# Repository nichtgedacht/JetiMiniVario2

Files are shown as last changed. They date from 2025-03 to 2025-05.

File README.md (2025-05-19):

# JetiMiniVario2

## What it is
JetiMiniVario2 is a variometer and altimeter.
Optionally, a Ublox GNSS module (M8 or M10) can be connected.

JetiMiniVario was developed to detect smallest air movements with a DLG.

Communication with the GNSS (GPS) device is done using the UBX protocol over UART.
If the device is set to 9600 baud before (factory setting) the necessary
configuration is done automatically. The NavPvt data set with 10Hz refresh rate
is used. The serial interface works with 19200 baud.

Communication with the RC-receiver (Jeti EX Bus) is done with a low level 
configured UART Peripheral at 125000 Baud. It works half duplex on a single pin.
The DMA is used in order to achieve a proper timing without collisions.

Communication with the sensor boards is done over I2C at 500kHz. 

JetiMiniVario2 is built from the following components:

 * A MCU board Seeed Studio XIAO (SAMD21G18)

 * One or two shield boards with the SPL06-001 Barometric Pressure Sensor

 * A GNSS device with a M8 or M10 module from Ublox. (i.e. Beitian BN-XXX BE-XXX, FlyfishRC M10 mini, ...) 

JetiMiniVario is optimized for very short response times
with low noise. Due to a free RC channel the filtering can be
adjusted continuously and thus the variometer can be be calmed down.
A gas-tight volume is provided between the sensor boards.
By encapsulating the sensor PCBs with thin epoxy plates and attaching
a tube connection one sensor can be connected to a TEK probe. 

A voltage divider 1:10 (recommended 2k and 18k each 0.1%) can be connected
to PIN_A8. The 3.3V are used as reference so a voltage up to 33V can be
applied. Accuracy is 1/100 V if calibrated, see below.

Up to 4 Servos can be connected. The timing of the pulses (period) can
be adjusted from 10 to 40 ms. The mapping to the RC-channels of the the
EX-Bus is arbitary. Failsave positions can be adjusted for each servo.
The time from a fail to failsave is adjustable also.

There is a watchdog which monitors the main loop. If the loop time
exceeds 7.8 ms all sensors are bypassed and a fuse becomes triggered
within the configuration. If the loop time exceeds even 31 ms a system
reset becomes triggered also. This way the servo control is save in
case of a sensor hardware is blocking or delaying the loop.

The fuse can be set again by the terminal, see below.

Please use the bootloader from here:
https://github.com/adafruit/uf2-samdx1/releases
This bootloader has the brown-out detector implemented.
It prevents bootloader corruption due to unclean power cycles.
Please find it also within the UF2 folder.

## Mechanical design

The device can be assembled from several hardware parts according
to your individual needs. It could be a very small thing with the MCU-board only
or the full featured device with a baseboard.

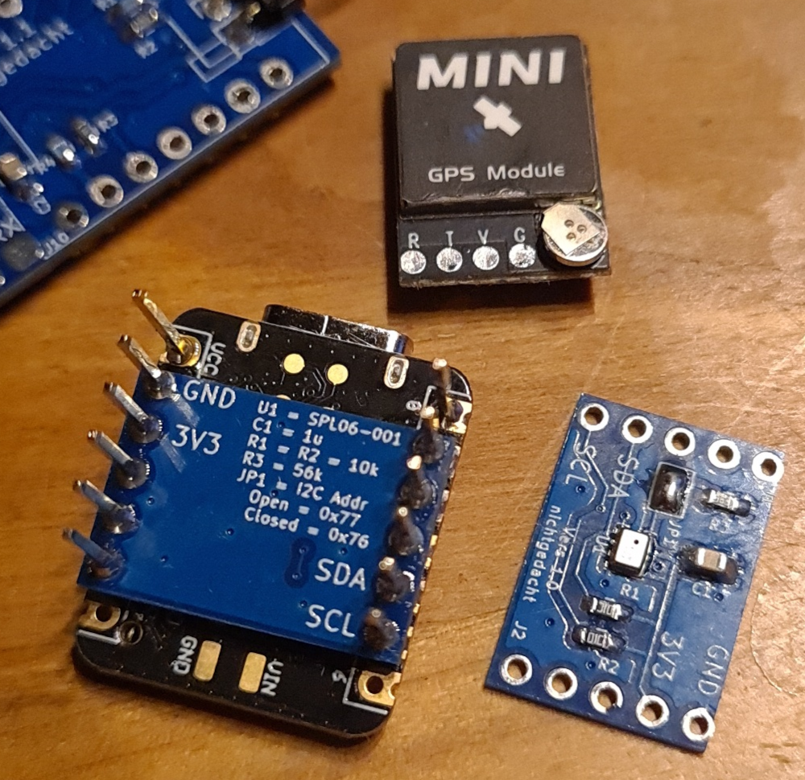
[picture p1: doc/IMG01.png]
  
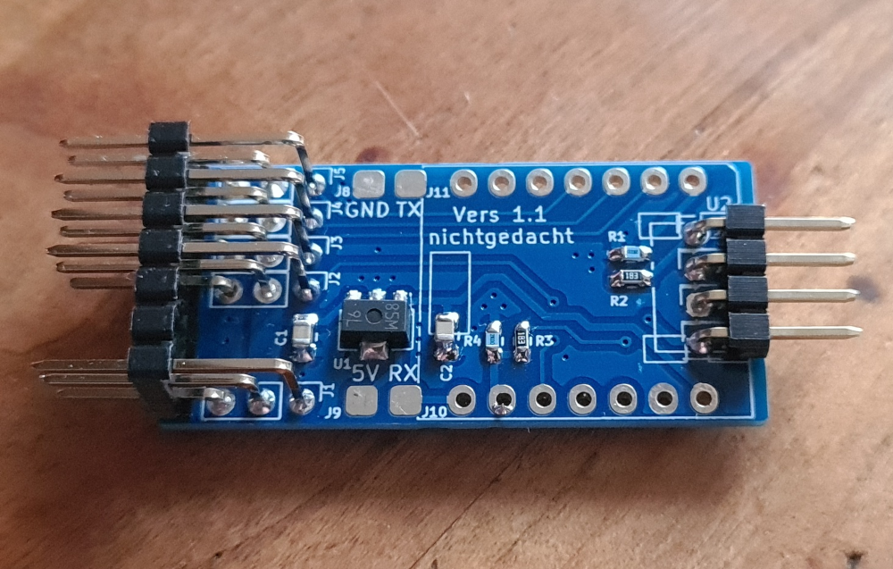
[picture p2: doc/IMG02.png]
  

The Sensor PCB has a Solder Jumper for changing the I2C address.
If 2 PCB's are in use, the sensor vwith the changed address becomes the
encapsulated one for TEK connection.  

First set the alternative address on one of the Sensors:  
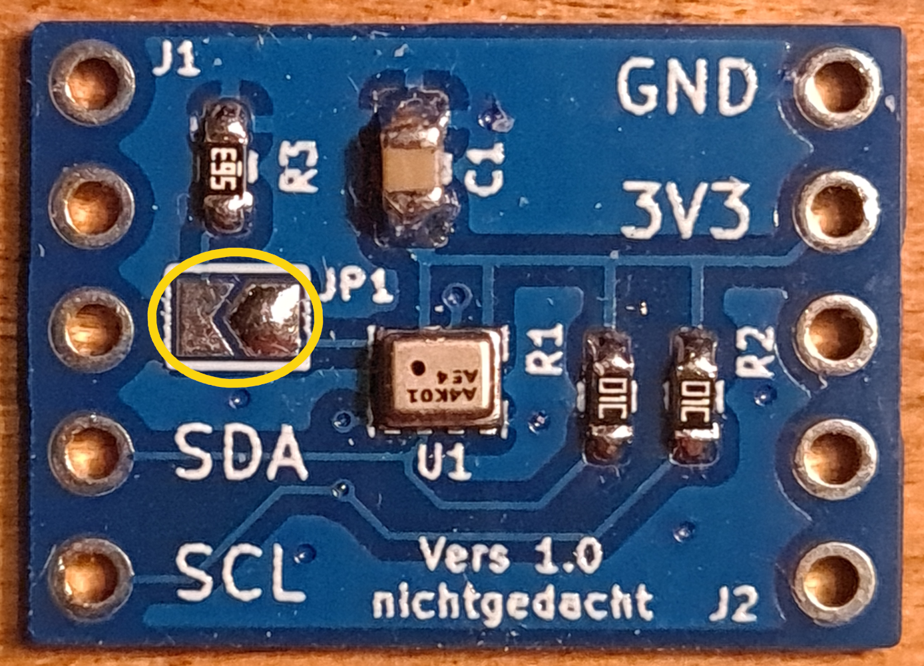
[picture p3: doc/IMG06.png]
  

In order to encapsulate a volume by the 2 sensor PCB's 
make both PCBs gasproof by using some epoxy on this sides:  
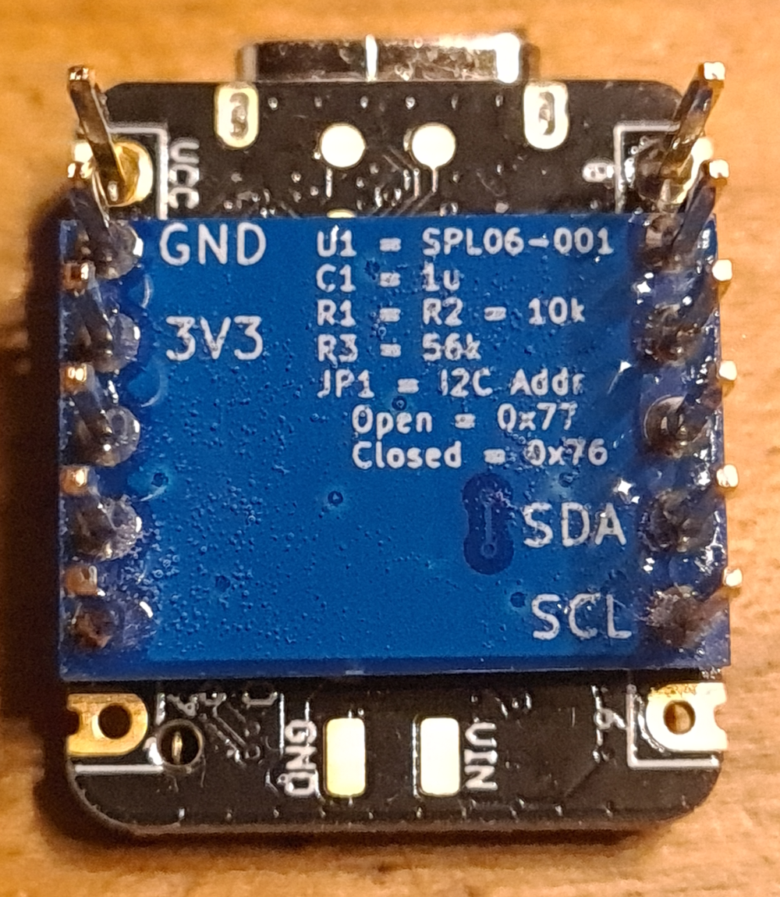
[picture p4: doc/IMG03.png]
  

The sensor PCB's then can be stacked and encapsulate an air volume together with small epoxy stripes
Please refer to first version of JetiMiniVario:  
  

Top view
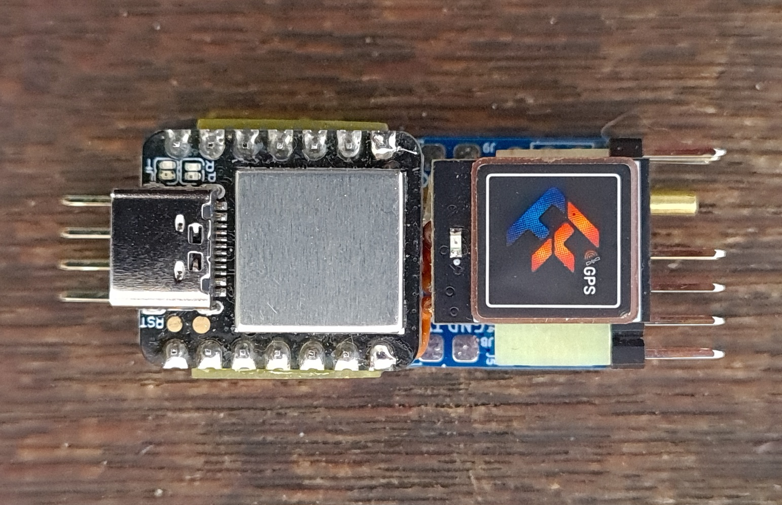
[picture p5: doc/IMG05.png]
  

Sensor PCB:  
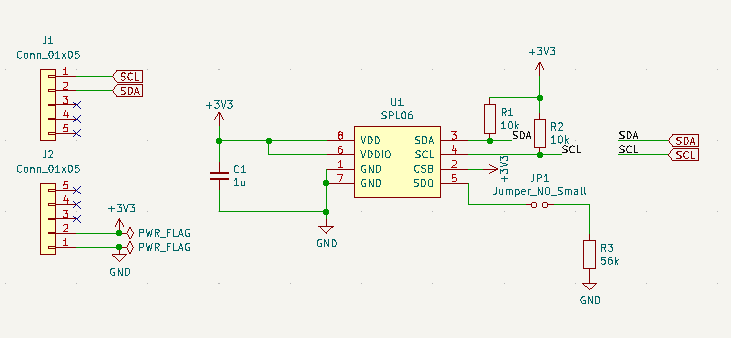
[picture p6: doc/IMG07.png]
  

Base PCB:  
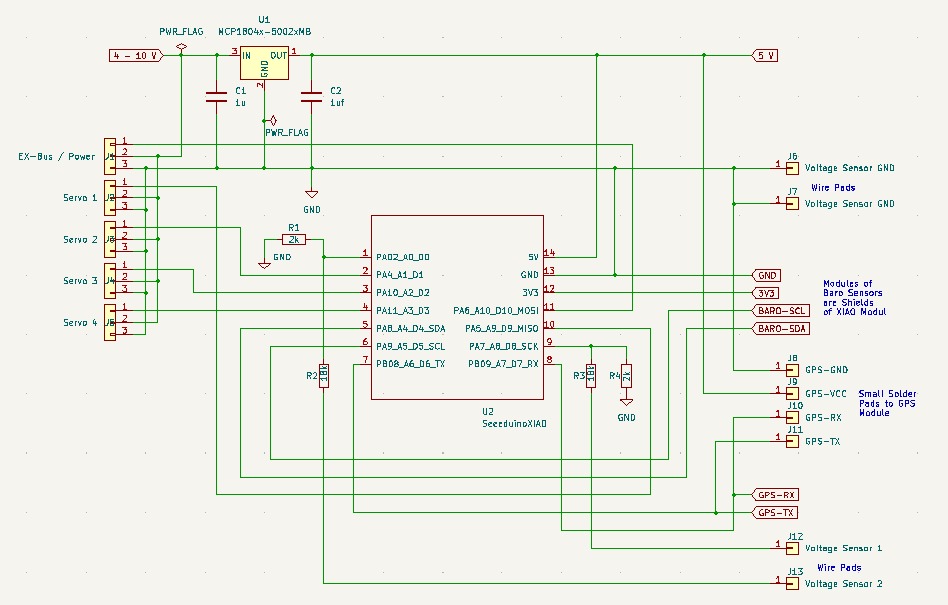
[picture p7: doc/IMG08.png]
  

## Electrical limits

JetiMiniVario can be powered by the RC receiver.
The voltage should not not exceed 6V. The voltage regulator
on the XIAO has 7V as absolut maximum rating. 4 cells of NiMh
are probably ok. But most GNSS-modules are specified for max 5.5V
So it's better using a 5.5V BEC or an onboard LDO regulator like the
AMS1117 5.0V type, if the input voltage exceeds 5.5V. The current baseboard
uses an MCP1804 5V type. Power from 1 cell LiPo is perfectly ok for the
device itself and the GNSS-modul. The 3.3V regulator of the XIAO can power
the baro-sensor-pcbs VCC-pins in any setup.

## Software

### Libraries

The software uses two libraries:
* DPS
* JetiExBus

To load the two libs at the same time you can use this command line:

git clone --recursive https://github.com/nichtgedacht/JetiMiniVario2.git 
 
### IDE 
 
The repository here is to be used directly as a PlatformIO project.
It is as simple as:

* Install VSCode

* In VSCode install the PlatformIO extension. (Search by typing Plat...)

* Within PlatformIO open the directory of the repository as a project.
 
Because the Arduino Framework is used, the code can also be compiled in the Arduino IDE. 
For this, the extension for the SeedStudio XIAO must be installed first.
Then main.cpp must be renamed to JetiMiniVario.ino.
The correct board can then be selected in the board selection.

### Upload

Until the GNSS module was connected, the software was developed with a BlackMagicProbe
which also used the serial interface at A6 A7. 
The upload was done via the debug interface. In the current configuration
the upload is done via the USB-C connector.
It is of course still possible to work with the BlackMagicProbe if the
debug Serial.print goes through the USB-C connector. See "platformio.ini".
<BR>
<BR>
You can upload also one of the UF2 files:
* Short the reset contacts 2 times within 1/2 second.
* The yellow LED will slowly dim blink.
* The device will then register as mass storage
* Copy the UF2 file there

### LED Signals of application

* Yellow LED blinks 1Hz

For configurations without SERVO and with BARO (DUAL).<br>
Baro Hardware is missing or broken.<br>
Terminalserver can not be reached in this state.

* RX- and TX-LED (blue) solid on

For configurations with SERVO.<br>
Watchdog has triggered the fuse. Reset fuse with a terminal <br>
after checking the hardware.

* Yellow LED blinks 10Hz.

Normal operation with GPS (GNSS-modul).

* RX- and TX-LED (blue) and yellow LED solid on

Hard fault

### Configuration

There are only these defines at the beginning of config.h:
* //#define DEBUG // debug prints or not

* #define BARO // using a barometric pressure sensor<br>

* #define DUAL // using an additional barometric pressure sensor<br>

    If dual pressure sensors are used one is for the variometer and the other becomes<br>
    altitude.

* #define GPS  // using the GNSS Modul<br>

* #define VOLT // using the ADC<br>

* #define SERVO // enable servo output<br>
 
These defines depends on the assembled hardware. Please comment out what is not used<br>
or use the appropriate UF2 file
<br>
<br>

All other configuration can be done with a Command-Line-Interface:  

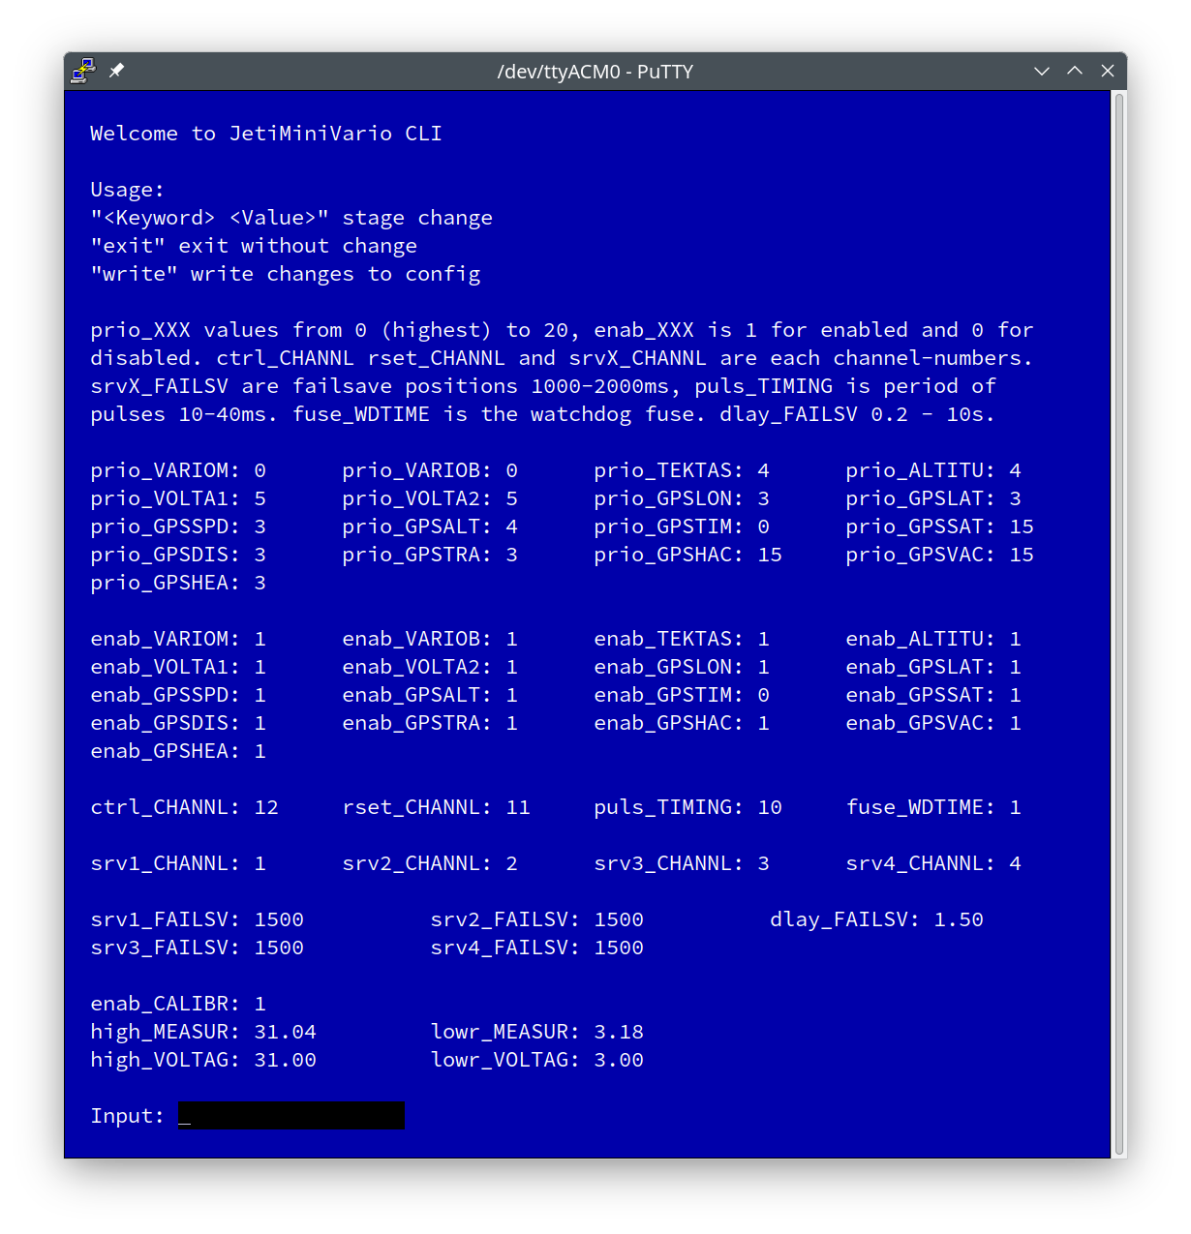
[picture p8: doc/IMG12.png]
  

The following items can be configured with the CLI

* The RC-channel used for live adjusting the filters.<br>

  This RC-channel-value is assumed to go from 1000us to 2000us.<br>
  Time constants (Taus) of the main filter are then adjustable from about 0.4s (at 1000us)<br>
  to about 0.8s (at 2000us)<br>

* The RC-channel used to reset altitude and GNSS home position<br>

  The transition of channel value for reset must go from higher to lower<br>
  and difference must be greater than 300 (e.g. from 2000 to 1000 ).<br>
  Hint: Use the Servo Monitor. The transition must be instantanuosly.<br>
  If this switch is used for changing a flight mode also and there is a delay<br>
  i.e. a soft transition the reset will not work

* Priority of a sensor<br>

* Enable/disable a sensor<br>  

* The RC-channel-mapping to the servo outputs<br>  

* Period of servo pulses timing in ms<br>  

* Failsave positions in micro s<br>  

* Delay to failsave in s<br>  

* Fuse of watchdog timer reset/set<br>  
 
* Calibrate the voltage sensor (ADC)<br>  

For calibrating the voltage sensor:
* Disable calibration
* Apply a voltage arround 3V
* Read the measured voltage
* Change the values for applied and measured voltages
* Do the same for a voltage arround 30V
* Enable calibration
* Write changes

Note that this calibration works precisely only for
the selected pin (VOLTA1 or VOLTA2). The deviation
of the other voltage then depends on the accuracy of
the choosen resistors.    

Legend:
* VARIOM Variometer
* VARIOB in DUAL-setup Variometer from static port no TEK
* TEKTAS True Airspeed calculated from Pressure Diff of TEK-Probe
* ALTITU Barometric Altitude
* VOLTA1 Voltage1
* VOLTA2 Voltage2
* GPSLON GPS Longtitude
* GPSLAT GPS Latitude
* GPSSPD GPS Speed
* GPSALT GPS Altitude
* GPSTIM GPS Time
* GPSSAT Number GPS Vehicles in use
* GPSDIS Calculated Value of GPS Distance to Home Position
* GPSTRA Calculated Value of GPS Travel Distance
* GPSHAC GPS Horizontal Accuracy
* GPSVAC GPS Vertical Accuracy
* GPSHEA GPS Bearing

As terminal emulation Putty can be used. The default settings<br>
of Putty are ok.<br>
* Just select the serial interface connected to the device<br>
* At least 83x38 (rows x colums) are needed for a complete window.<br>
* For proper viewing an 11 point Monospace Font is recommended.<br> 
* Putty is available for Linux, and Windows.

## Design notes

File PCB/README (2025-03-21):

View a Set of Gerbers by uploading to https://tracespace.io/view/

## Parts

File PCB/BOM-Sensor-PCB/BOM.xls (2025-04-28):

Comment | Designator | Footprint | JLCPCB Part#(optional)
1uF | C1 | 0805 | C28323
10k | R1, R2, R3 | 0603 | C25804
SPA06-003 | U1 | LGA8 | C30589048

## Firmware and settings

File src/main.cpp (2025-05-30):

#include "JetiExBusProtocol.h"  //	https://github.com/nichtgedacht/JetiExBus
#include <Wire.h>
#include "DPS.h"                //	https://github.com/nichtgedacht/DPS2
#include "config.h"

config_t cfg;

JetiExBusProtocol exBus;

// Connect to DPS
DPS dpsA;  // gets DPS_ADDR_DEF 0x77
DPS dpsB;  // gets DPS_ADDR_ALT 0x76

#define T1 150000.0 // base time constant
#define T2 200000.0 // base time constant
double t1 = T1;
double t2 = T2;

#define deltaTA 31250  // measured value differs a bit from
                       // device to device nominal value could
#define deltaTB 31250  // be 5% off or so.

// set neutral
uint16_t channelValue = 1500;
uint16_t prevChannelValue = 1500;

bool servoRun = false;
bool wdRun = false;
ulong rcWatch;

bool resetHome = true;
double latHome;
double lonHome;
double latLast;
double lonLast;
uint32_t travel = 0;

ulong blink;

volatile bool wdTimeout = false;

long mue = 0;
long mueDiff = 0;
long prevMue = 0;
long worstMueDiff = 0;
unsigned long loopCount = 0;


//uint32_t mic, prevmic, micDiff;
//double micDiffAvr;
//char micDiffAvr_string[20];

long realPressureA, realPressureB;
int32_t pressureA[1], pressureB[1];
int32_t temperatureA[1], temperatureB[1];

#ifdef GPS
// sets refresh rate
char refresh_10hz[] = { 0xb5, 0x62, 0x06, 0x08, 0x06, 0x00, 0x64, 0x00,
                        0x01, 0x00, 0x01, 0x00, 0x7a, 0x12 };

// sets messages 
char ubx_nav_pvt[] = { 0xb5, 0x62, 0x06, 0x01, 0x08, 0x00, 0x01, 0x07,
                       0x00, 0x01, 0x00, 0x00, 0x00, 0x00, 0x18, 0xe1 };

// sets port
char prt_ubx_only_19200[] = { 0xb5, 0x62, 0x06, 0x00, 0x14, 0x00, 0x01, 0x00,
                              0x00, 0x00, 0xd0, 0x08, 0x00, 0x00, 0x00, 0x4b,
                              0x00, 0x00, 0x07, 0x00, 0x01, 0x00, 0x00, 0x00,
                              0x00, 0x00, 0x46, 0x4b };


char enable_galileo[] = { 0xb5, 0x62, 0x06, 0x3e, 0x0c, 0x00, 0x00, 0x00,
                          0x20, 0x01, 0x02, 0x04, 0x08, 0x00, 0x01, 0x00,
                          0x01, 0x01, 0x82, 0x56 };
#endif

enum {
    ID_DUMMY = 0,
#ifdef BARO
    ID_VARIOM,
#ifdef DUAL
    ID_VARIOB,
    ID_TEKTAS,
#endif
    ID_ALTITU,
#endif
#ifdef GPS
    ID_GPSLON,
    ID_GPSLAT,
    ID_GPSSPD,
    ID_GPSALT,
    ID_GPSTIM,
    ID_GPSVEH,
    ID_GPSDIS,
    ID_GPSTRA,
    ID_GPSHAC,
    ID_GPSVAC,
    ID_GPSHEA,
#endif
#ifdef VOLT
    ID_VOLTA1,
    ID_VOLTA2,
#endif
};

#ifdef BARO
double referencePressureA = 0, referencePressureB = 0, offsetPressureB = 0;
double r_altitudeA = 0, r_altitude0A = 0, r_altitudeB = 0, r_altitude0B = 0; 
double climbA = 0, climb0A = 0, climbB = 0, climb0B = 0; 
double dyn_alfaA, dyn_alfaB, alfa_1A, alfa_2A, alfa_1B, alfa_2B, factor;

uint32_t diff_t_A, max_diff_t_A, diff_t_B, max_diff_t_B;
double relativeAltitudeA = 0, relativeAltitudeB = 0;
#endif

#ifdef VOLT
double avar1 = 0;
double avar2 = 0;
uint16_t GAIN_CORR;
uint16_t OFFSET_CORR;
bool adcStart = true;
#endif
int j=0;

#ifdef GPS
//-------------------- UBX ----------------------------

typedef union {

    struct {
                                /* Comments stohlen from PX4 */
	    uint32_t iTOW;          /**< GPS Time of Week [ms] */
	    uint16_t year;          /**< Year (UTC)*/
	    uint8_t  month;         /**< Month, range 1..12 (UTC) */
	    uint8_t  day;           /**< Day of month, range 1..31 (UTC) */
	    uint8_t  hour;          /**< Hour of day, range 0..23 (UTC) */
	    uint8_t  min;           /**< Minute of hour, range 0..59 (UTC) */
	    uint8_t  sec;           /**< Seconds of minute, range 0..60 (UTC) */
	    uint8_t  valid;         /**< Validity flags (see UBX_RX_NAV_PVT_VALID_...) */
	    uint32_t tAcc;          /**< Time accuracy estimate (UTC) [ns] */
	    int32_t  nano;          /**< Fraction of second (UTC) [-1e9...1e9 ns] */
	    uint8_t  fixType;       /**< GNSSfix type: 0 = No fix, 1 = Dead Reckoning only, 2 = 2D fix, 3 = 3d-fix, 4 = GNSS + dead reckoning, 5 = time only fix */
	    uint8_t  flags;         /**< Fix Status Flags (see UBX_RX_NAV_PVT_FLAGS_...) */
	    uint8_t  flags2;        /**< Additional flags */
	    uint8_t  numSV;         /**< Number of SVs used in Nav Solution */
	    int32_t  lon;           /**< Longitude [1e-7 deg] */
	    int32_t  lat;           /**< Latitude [1e-7 deg] */
	    int32_t  height;        /**< Height above ellipsoid [mm] */
	    int32_t  hMSL;          /**< Height above mean sea level [mm] */
	    uint32_t hAcc;          /**< Horizontal accuracy estimate [mm] */
	    uint32_t vAcc;          /**< Vertical accuracy estimate [mm] */
	    int32_t  velN;          /**< NED north velocity [mm/s]*/
	    int32_t  velE;          /**< NED east velocity [mm/s]*/
	    int32_t  velD;          /**< NED down velocity [mm/s]*/
	    int32_t  gSpeed;        /**< Ground Speed (2-D) [mm/s] */
	    int32_t  headMot;       /**< Heading of motion (2-D) [1e-5 deg] */
	    uint32_t sAcc;          /**< Speed accuracy estimate [mm/s] */
	    uint32_t headAcc;       /**< Heading accuracy estimate (motion and vehicle) [1e-5 deg] */
	    uint16_t pDOP;          /**< Position DOP [0.01] */
	    uint16_t flags3;        /**< Additional flags */
	    uint32_t reserved1;     /**< reserved */
	    int32_t  headVeh;       /**< (ubx8+ only) Heading of vehicle (2-D) [1e-5 deg] */
	    int16_t  magDec;        /**< magnetc declination */
        uint16_t magAcc;        /**< magnetic accelaration */

    } Val;

    uint8_t UBXBuffer[92];

} NavPvt_t;

typedef union {

    struct {
                         /* Comments stohlen from PX4 */
	    uint32_t iTOW;   /**< GPS Time of Week [ms] */
	    int32_t  lon;    /**< Longitude [1e-7 deg] */
	    int32_t  lat;    /**< Latitude [1e-7 deg] */
	    int32_t  height; /**< Height above ellipsoid [mm] */
	    int32_t  hMSL;   /**< Height above mean sea level [mm] */
	    uint32_t hAcc;   /**< Horizontal accuracy estimate [mm] */
	    uint32_t vAcc;   /**< Vertical accuracy estimate [mm] */

    } Val;

    uint8_t UBXBuffer[28];

} NavPosllh_t;

enum UBXFrameState
{
	WaitStart1,
    WaitStart2,
	WaitClass,
    WaitID,
	WaitLen1,
    WaitLen2,
    WaitPayload,
    WaitChk2
};

UBXFrameState state = WaitStart1;
NavPvt_t NavPvt;
NavPosllh_t NavPosllh;

uint16_t distanceHome(double lonRemote, double latRemote ) {

    double dx = 1113000 * cos( ( latHome * PI ) / 180 ) * ( lonHome - lonRemote); 
    double dy = 1113000 * ( latHome - latRemote);
    return round ( sqrt( dx * dx + dy * dy ) ); // distance in decimeter
}

uint16_t distanceTravel(double lonCurrent, double latCurrent ) {

    uint16_t step;

    double dx = 1113000 * cos( ( latLast * PI ) / 180 ) * ( lonLast - lonCurrent); 
    double dy = 1113000 * ( latLast - latCurrent);

    step =  round ( sqrt( dx * dx + dy * dy ) ); // distance in decimeter

    if (step > 20) {
        latLast = latCurrent;
        lonLast = lonCurrent;
        travel += step ;
    }
    return travel / 10;
}

void DecodeUBX(uint8_t Class, uint8_t ID) {

    bool valid = false;
    double lat = 0, lon = 0;

    if ( Class == 1 && ID == 7 ) {

        if ( NavPvt.Val.fixType == 3 ) {
            valid = true;
            lat = (double)NavPvt.Val.lat/10000000; // degree
            lon = (double)NavPvt.Val.lon/10000000; // degree
            if ( resetHome ) {
                resetHome = false;
                latLast = latHome = lat;
                lonLast = lonHome = lon;
                travel = 0;
            }
        }

        exBus.SetSensorValueGPS (ID_GPSLAT, false, lat, valid);
        exBus.SetSensorValueGPS (ID_GPSLON, true,  lon, valid);
        exBus.SetSensorValue (ID_GPSALT, round(NavPvt.Val.hMSL/100), valid);
        exBus.SetSensorValue (ID_GPSSPD, round(NavPvt.Val.gSpeed/10), valid);
        exBus.SetSensorValueTime(ID_GPSTIM, NavPvt.Val.hour, NavPvt.Val.min, NavPvt.Val.sec, valid);
        exBus.SetSensorValue (ID_GPSVEH, NavPvt.Val.numSV, valid);
        exBus.SetSensorValue (ID_GPSDIS, distanceHome(lon, lat), valid);
        exBus.SetSensorValue (ID_GPSTRA, distanceTravel(lon, lat), valid);
        exBus.SetSensorValue (ID_GPSHAC, round(NavPvt.Val.hAcc/100), valid);
        exBus.SetSensorValue (ID_GPSVAC, round(NavPvt.Val.vAcc/100), valid);
        exBus.SetSensorValue (ID_GPSHEA, round(NavPvt.Val.headMot/10000), valid);
    }

#ifdef DEBUG
    SerialUSB.print(NavPvt.Val.numSV);
    SerialUSB.println(" vehicles");    

    switch ( NavPvt.Val.fixType ) {

        case 0: 
            SerialUSB.println("no fix");
            break;
        case 2:
            SerialUSB.println("2d fix");
            break;
        case 3:
            SerialUSB.println("3d fix");
            break;
    } 
#endif
}

void parse_UBX_NAV(char c) {

    static int i;
    static uint16_t UBXLengt;
    static uint8_t length1;
    static uint8_t UBXClass;
    static uint8_t UBXID;
    static uint8_t CheckSumA;
    static uint8_t CheckSumB;
    static uint8_t UBXChkA;
    static uint8_t UBXChkB;
    static uint16_t UBXPayloadLength;
    static uint8_t *buffer;

    switch ( state ) {

        case WaitStart1: 
            if ( c == 0xb5 ) { 
                CheckSumA = 0;
                CheckSumB = 0;
                state = WaitStart2;
            }
            break;

        case WaitStart2:
            if ( c == 0x62 ) {
                state = WaitClass;
            }
            break;

        case WaitClass:
            UBXClass = c;
            CheckSumA = CheckSumA + c;
            CheckSumB = CheckSumB + CheckSumA;
            state = WaitID;
            break;

        case WaitID:
            UBXID = c;
            CheckSumA = CheckSumA + c;
            CheckSumB = CheckSumB + CheckSumA;

            switch (UBXID) {
                case 7:
                    UBXPayloadLength = 92;
                    buffer = &NavPvt.UBXBuffer[0];
                    state = WaitLen1;
                    break;
                case 2:
                    UBXPayloadLength = 28;
                    buffer = &NavPosllh.UBXBuffer[0];
                    state = WaitLen1;
                    break;
                default:
#ifdef DEBUG
                    SerialUSB.print("no decoder for NAV-ID: ");
                    SerialUSB.println(UBXID);
#endif
                    state = WaitStart1;
                    break;
            }
            break;

        case WaitLen1:
            length1 = c;
            CheckSumA = CheckSumA + c;
            CheckSumB = CheckSumB + CheckSumA;
            state = WaitLen2;
            break;

        case WaitLen2:
            UBXLengt = (c << 8) | length1;
            CheckSumA = CheckSumA + c;
            CheckSumB = CheckSumB + CheckSumA;

            if ( UBXLengt == UBXPayloadLength) {
                state = WaitPayload;
                i = 0;
            } else {
                state = WaitStart1; // error, try again
#ifdef DEBUG
                SerialUSB.println("error UBXLengt");
#endif
                state = WaitStart1;
            }
            break;

        case  WaitPayload:
            if ( i < UBXLengt ) {
                buffer[i++] = c;
                CheckSumA = CheckSumA + c;
                CheckSumB = CheckSumB + CheckSumA;
            }  else {
                UBXChkA = c;
                state = WaitChk2;
            }
            break;

        case  WaitChk2:
            UBXChkB = c;
            if ( CheckSumA == UBXChkA && CheckSumB == UBXChkB ) {
                DecodeUBX(UBXClass, UBXID);
                digitalWrite( PIN_LED_13, LOW);
                blink = millis();
            }
            state = WaitStart1;
            break;

        default:
            state = WaitStart1;
            break;
    }
}

// -------------------- /UBX ---------------------------
#endif

void startWatchdog(void) {

    static bool initialized;

    if ( !initialized ) {

        REG_GCLK_GENDIV = GCLK_GENDIV_DIV (1) |             // Use the undivided 32.768kHz clock source
                          GCLK_GENDIV_ID (2);               // Select Generic Clock (GCLK) 2
        while ( GCLK->STATUS.bit.SYNCBUSY );                // Wait for synchronization

        REG_GCLK_GENCTRL = GCLK_GENCTRL_GENEN |             // Enable GCLK2
                           GCLK_GENCTRL_SRC_OSCULP32K |     // Set the clock source to the ultra low power oscillator (OSCULP32K)
                           GCLK_GENCTRL_ID (2);             // Select GCLK2
        while ( GCLK->STATUS.bit.SYNCBUSY );                // Wait for synchronization

        // Feed GCLK2 to WDT (Watchdog Timer)
        REG_GCLK_CLKCTRL = GCLK_CLKCTRL_CLKEN |             // Enable GCLK2 to the WDT
                           GCLK_CLKCTRL_GEN_GCLK2 |         // Select GCLK2
                           GCLK_CLKCTRL_ID_WDT;             // Feed the GCLK2 to the WDT
        while ( GCLK->STATUS.bit.SYNCBUSY );                // Wait for synchronization

        // Set up WDT
        REG_WDT_EWCTRL = WDT_EWCTRL_EWOFFSET_256;           // Set the Early Warning Interrupt Time Offset to 7.8125 ms
        REG_WDT_INTENSET = WDT_INTENSET_EW;                 // Enable the Early Warning interrupt
        REG_WDT_CONFIG = WDT_CONFIG_PER_1K;                 // Set the WDT reset timeout to 31.25 ms
        REG_WDT_CTRL = WDT_CTRL_ENABLE;                     // Enable the WDT in normal mode
        while (WDT->STATUS.bit.SYNCBUSY);                   // Await synchronization of registers between clock domains

        // Configure and enable WDT interrupt
        NVIC_SetPriority(WDT_IRQn, 0);                      // Top priority
        NVIC_EnableIRQ(WDT_IRQn);

        initialized = true;

    } else {

       REG_WDT_CTRL = WDT_CTRL_ENABLE;
       while(WDT->STATUS.bit.SYNCBUSY);

    }
}

void stopWatchdog(void) {
    REG_WDT_CTRL = 0x00;
    while(WDT->STATUS.bit.SYNCBUSY);
}

// resets referencePressure and set reset flag for GPS
void altiZero(void) {
#ifdef BARO
    referencePressureA = dpsA.getSeaLevel(referencePressureA, - r_altitude0A);
#ifdef DUAL
    referencePressureB = dpsB.getSeaLevel(referencePressureB, - r_altitude0B);
    // used for TAS, calc offset again when reset altitude to zero
    offsetPressureB = referencePressureA - referencePressureB;
#endif
#endif
    resetHome = true; // GPS Home
}

void WDT_Handler() {

#ifdef SERVO
    if ( cfg.fuse_WDTIME == 1) {
       cfg.fuse_WDTIME = 0;
       writeConfig(cfg);
    }
#endif

    wdTimeout = true;    // set here for short block and timely reset of WDT

    // indicate an error
    digitalWrite( PIN_LED_TXL, LOW);
    digitalWrite( PIN_LED_RXL, LOW);

    while ( WDT->STATUS.bit.SYNCBUSY );               // Wait for synchronization
    REG_WDT_INTFLAG = WDT_INTFLAG_EW;                 // Clear interrupt flag
    while ( WDT->STATUS.bit.SYNCBUSY );               // Wait for synchronization
}
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
void loop () {

#ifdef SERVO
    if (!wdRun) {
        ++loopCount;
        if ( loopCount == 10) {
            startWatchdog();
            wdRun = true;
            //delay(40);
        }
    }
    //   else {
    //    ++loopCount;
    //    if (loopCount == 40000) {
    //        delay(10);
    //        SerialUSB.println(loopCount);
    //    }
    //}
#endif

#ifdef SERVO
    if (!WDT->STATUS.bit.SYNCBUSY) {            // let it synchronize while loop is running
        REG_WDT_CLEAR = WDT_CLEAR_CLEAR_KEY;    // Clear the watchdog timer
    }
#endif

#ifndef DEBUG
    if ( USB->DEVICE.DADD.reg &USB_DEVICE_DADD_ADDEN ) {    // if plugged in, fast check

#ifdef SERVO
        stopWatchdog();
#endif
        if ( SerialUSB ) { // if connected, slow check
            cliConf();
        }
    }
#endif

#ifdef VOLT
    uint32_t ar1 = analogRead(PIN_A8);
    if (adcStart) {
        avar1 = ar1;
        adcStart = false;
    }
    avar1 = avar1 - 0.01 * ( avar1 - (double) ar1); // avarage by exponential filter
    double voltage1 = (3.3 * avar1 ) / 409.6;     // assume 1:10 voltage divider

    uint32_t ar2 = analogRead(PIN_A0);
    if (adcStart) {
        avar2 = ar2;
        adcStart = false;
    }
    avar2 = avar2 - 0.01 * ( avar2 - (double) ar2); // avarage by exponential filter
    double voltage2 = (3.3 * avar2 ) / 409.6;     // assume 1:10 voltage divider
#endif

#ifdef SERVO
    if ( rcWatch + cfg.dlay_FAILSV * 1000 < millis() ) {

        TCC0->CC[0].reg = cfg.srv3_FAILSV;
        while (TCC0->SYNCBUSY.bit.CC0);

        TCC0->CC[1].reg = cfg.srv4_FAILSV;
        while (TCC0->SYNCBUSY.bit.CC1);

        TCC0->CC[2].reg = cfg.srv2_FAILSV;
        while (TCC0->SYNCBUSY.bit.CC2);

        TCC0->CC[3].reg = cfg.srv1_FAILSV;
        while (TCC0->SYNCBUSY.bit.CC3);

    }
#endif

    if ( exBus.HasNewChannelData() ) {

#ifdef SERVO
        if ( servoRun ) {
            rcWatch = millis();
        } else {
            servoRun = true;
            // Enable output (start PWM)
            TCC0->CTRLA.reg |= (TCC_CTRLA_ENABLE);
            while (TCC0->SYNCBUSY.bit.ENABLE);              // Wait for synchronization
        }

        TCC0->CC[0].reg = exBus.GetChannel(cfg.srv3_CHANNL);
        while (TCC0->SYNCBUSY.bit.CC0);

        TCC0->CC[1].reg = exBus.GetChannel(cfg.srv4_CHANNL);
        while (TCC0->SYNCBUSY.bit.CC1);

        TCC0->CC[2].reg = exBus.GetChannel(cfg.srv2_CHANNL);
        while (TCC0->SYNCBUSY.bit.CC2)

        TCC0->CC[3].reg = exBus.GetChannel(cfg.srv1_CHANNL);
        while (TCC0->SYNCBUSY.bit.CC3);
#endif

#ifdef BARO
        if (!wdTimeout) {
            // channel controls time constant
            channelValue = exBus.GetChannel(cfg.ctrl_CHANNL);

            // channelValue can be 0 sometimes if RC transmitter is started after the receiver
            if (channelValue > 0) {
                //char buf[30];
                //sprintf(buf, "chan-%d: %.4d", 12, channelValue);
                //SerialUSB.println(buf);

                // make time constants variable
                // channel at 100% and no trimm -> 1000 - 2000
                // check in servo monitor !
                t1 = T1 + T1 * (  ( (double)channelValue - 1000 ) / 500 );
                t2 = T2 + T2 * (  ( (double)channelValue - 1000 ) / 500 );


                // recalc alfas from deltaT for remote controlled time constants
                // and handle them separately for both sensors
                alfa_1A = deltaTA / ( t1 + deltaTA );
                alfa_2A = deltaTA / ( t2 + deltaTA );

                alfa_1B = deltaTB / ( t1 + deltaTB );
                alfa_2B = deltaTB / ( t2 + deltaTB );

                // calc gain from remote controlled time constants
                factor = 1000000 / (t2 - t1);

                //dtostrf(T1, 6, 0, buf);
                //SerialUSB.println(buf);
            }
        } // wdTimeout
#endif //BARO

        // reset if cfg.rset_CHANNL has a lower value (Edge trigger)
        channelValue = exBus.GetChannel(cfg.rset_CHANNL);

        if (channelValue < prevChannelValue - 300)
            altiZero();

        prevChannelValue = channelValue;

    } // has new channel data

#ifdef BARO
    if (!wdTimeout) {

        if (dpsA.pressureAvailable() ) {

            realPressureA = dpsA.readPressure();

            relativeAltitudeA = dpsA.getAltitude (realPressureA, referencePressureA);

            r_altitude0A = r_altitude0A - alfa_1A * (r_altitude0A - relativeAltitudeA);

            r_altitudeA = r_altitudeA -  alfa_2A * (r_altitudeA - relativeAltitudeA);

            climb0A = (r_altitude0A - r_altitudeA) * factor;   // Factor is 1000000/dT ( 1/dT as seconds )

            // smoothing the climb value by another exponential filter
            // time constant of filter changes dynamically
            // greater speed of change means less filtering.
            // see "Nonlinear Exponential Filter"   
            dyn_alfaA = abs( (climbA - climb0A) / 0.4 );
            if ( dyn_alfaA >= 1 ) {
                dyn_alfaA = 1;
            }
            climbA = climbA - dyn_alfaA * ( climbA - climb0A );

#ifndef DUAL
            exBus.SetSensorValue (ID_VARIOM, round ((climbA) * 100), true);
#else
            exBus.SetSensorValue (ID_VARIOB, round ((climbA) * 100), true);
#endif
            exBus.SetSensorValue (ID_ALTITU, round ((r_altitude0A) * 10), true);
        }

#ifdef DUAL

        if (dpsB.pressureAvailable() ) {

            realPressureB = dpsB.readPressure();

            relativeAltitudeB = dpsB.getAltitude (realPressureB, referencePressureB);

            r_altitude0B = r_altitude0B - alfa_1B * (r_altitude0B - relativeAltitudeB);

            r_altitudeB = r_altitudeB -  alfa_2B * (r_altitudeB - relativeAltitudeB);

            climb0B = (r_altitude0B - r_altitudeB) * factor;   // Factor is 1000000/dT ( 1/dT as seconds )

            // smoothing the climb value by another exponential filter
            // time constant of filter changes dynamically
            // greater speed of change means less filtering.
            // see "Nonlinear Exponential Filter"   
            dyn_alfaB = abs( (climbB - climb0B) / 0.6 );
            if ( dyn_alfaB >= 1 ) {
                dyn_alfaB = 1;
            }
            climbB = climbB - dyn_alfaB * ( climbB - climb0B );

            exBus.SetSensorValue (ID_VARIOM, round ((climbB) * 100), true);

            double TAS = tAS( realPressureA, realPressureB );
            exBus.SetSensorValue (ID_TEKTAS, round (TAS), true);
        }

#endif
    } // wdTimeout
#endif //BARO

#ifdef VOLT
        exBus.SetSensorValue (ID_VOLTA1, round ((voltage1) * 100 ), true);
        exBus.SetSensorValue (ID_VOLTA2, round ((voltage2) * 100 ), true);
#endif


#ifdef GPS
    if (!wdTimeout) {

        if (millis() - blink > 20) {
            digitalWrite( PIN_LED_13, HIGH);
        }

        while ( Serial1.available())
        {
            // calls decodeUBX() 
            parse_UBX_NAV(Serial1.read());

        }

    } // wdTimeout
#endif

    exBus.DoJetiExBus();

} // loop

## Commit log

2025-04-28 added bootloader, some doc and production files
    [BOM.xls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]
2025-05-05 stay at a certain working framework, platform.ini
2025-05-19 fixed README and useless precision of TAS
    [main.cpp]
2025-05-30 bugfix reference pressure, range of time constants
    [main.cpp]
